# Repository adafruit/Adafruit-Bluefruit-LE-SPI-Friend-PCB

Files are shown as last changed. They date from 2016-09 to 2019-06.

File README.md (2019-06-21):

## Adafruit Bluefruit LE SPI Friend PCB

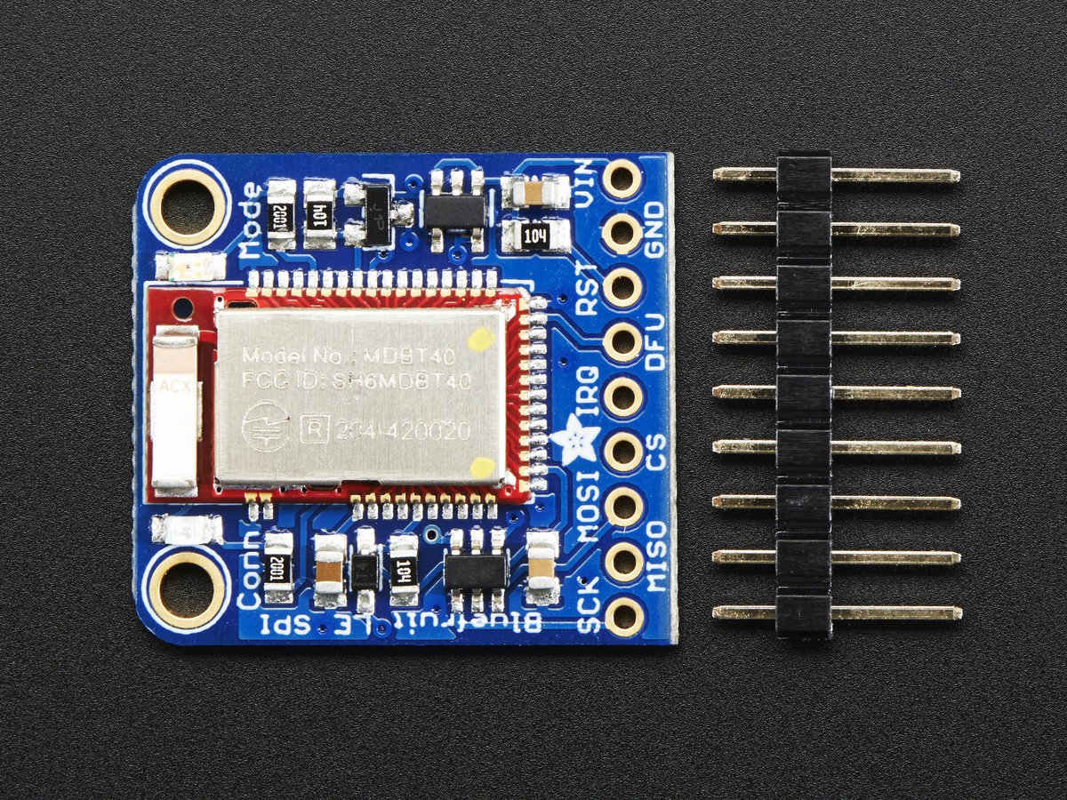
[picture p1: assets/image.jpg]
<a href="http://www.adafruit.com/products/2633"><br/>
Click here to purchase one from the Adafruit shop</a>

PCB files for the Adafruit Bluefruit LE SPI Friend PCB. Format is EagleCAD schematic and board layout
* https://www.adafruit.com/product/2633

### Description

The Bluefruit LE SPI Friend makes it easy to add Bluetooth Low Energy connectivity to anything with 4 or 5 GPIO pins. With SPI, you don't have to worry about baud rates, flow control, or giving up a hardware UART port. Connect to your Arduino or other microcontroller using the common four-pin SPI interface (MISO, MOSI, SCK and CS) plus a 5th GPIO pin for interrupts (to let the Arduino know when data or a response is ready).

This multi-function module can do quite a lot! For most people, they'll be very happy to use the standard Nordic UART RX/TX connection profile. In this profile, the Bluefruit acts as a data pipe, that can 'transparently' transmit back and forth from your iOS or Android device. You can use our iOS App or Android App, or write your own to communicate with the UART service.

### License

Adafruit invests time and resources providing this open source design, please support Adafruit and open-source hardware by purchasing products from [Adafruit](https://www.adafruit.com)!

Designed by Limor Fried/Ladyada for Adafruit Industries.

Creative Commons Attribution/Share-Alike, all text above must be included in any redistribution. See license.txt for additional details.

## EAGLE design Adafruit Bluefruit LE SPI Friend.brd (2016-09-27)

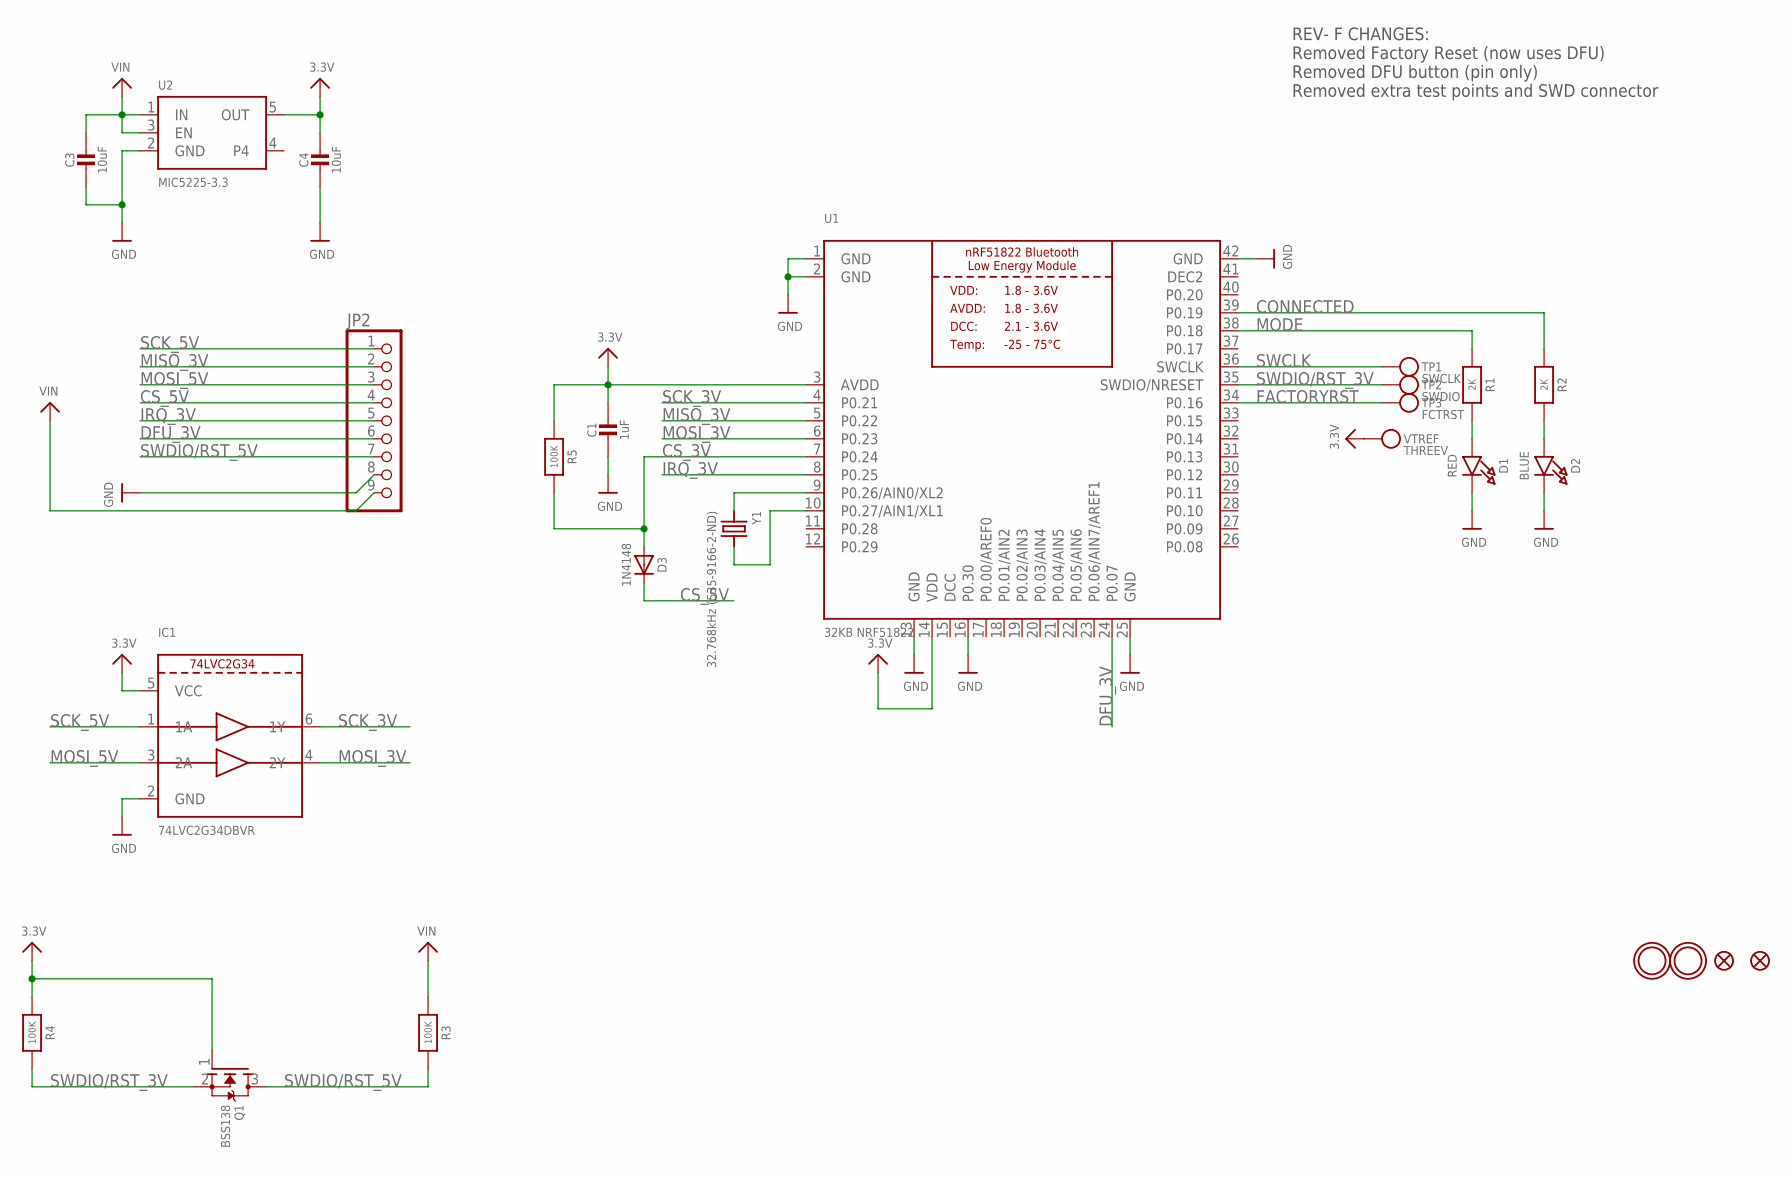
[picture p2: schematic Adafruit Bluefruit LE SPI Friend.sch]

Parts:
C1: 1uF; 0805_10MGAP
C3: 10uF; 0805-NO
C4: 10uF; 0805_10MGAP
D1: RED; CHIPLED_0805_NOOUTLINE
D2: BLUE; CHIPLED_0805_NOOUTLINE
D3: 1N4148; SOD-323
FID1, FID3: FIDUCIAL""; FIDUCIAL_1MM
IC1: 74LVC2G34DBVR; SOT23-6
JP2: HEADER-1X970MIL; 1X09_ROUND_70
Q1: BSS138; SOT23-WIDE@1
R1, R2: 2K; _0805MP
R3, R4: 100K; 0805-NO
R5: 100K; _0805MP
TP1: SWCLK; PAD-1.5X2.0
TP2: SWDIO; PAD-1.5X2.0
TP3: FCTRST; PAD-1.5X2.0
U1: 32KB NRF51822; BLE_MODULE_RAYTAC_MDBT40
U2: MIC5225-3.3; SOT23-5
U$28, U$29: MOUNTINGHOLE2.5; MOUNTINGHOLE_2.5_PLATED
VTREF: THREEV; PAD-1.5X2.0
Y1: 32.768kHz (535-9166-2-ND); CRYSTAL_CYL_2X6MM_SMT

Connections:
3.3V: C1.1, C4.1, IC1.5 (VCC), Q1.1 (G), R4.1, R5.1, U1.3 (AVDD), U1.14 (VDD), U2.5 (OUT), VTREF.P$1
CONNECTED: R2.1, U1.39 (P0.19)
CS_3V: D3.A, R5.2, U1.7 (P0.24)
CS_5V: D3.C, JP2.4
DCC: U1.15 (DCC)
DEC2: U1.41 (DEC2)
DFU_3V: JP2.6, U1.24 (P0.07)
FACTORYRST: TP3.P$1, U1.34 (P0.16)
GND: C1.2, C3.2, C4.2, D1.C, D2.C, IC1.2 (GND), JP2.8, U1.1 (GND), U1.2 (GND), U1.13 (GND), U1.16 (P0.30), U1.25 (GND), U1.42 (GND), U2.2 (GND)
IRQ_3V: JP2.5, U1.8 (P0.25)
MISO_3V: JP2.2, U1.5 (P0.22)
MODE: R1.1, U1.38 (P0.18)
MOSI_3V: IC1.4 (2Y), U1.6 (P0.23)
MOSI_5V: IC1.3 (2A), JP2.3
unnamed: U1.9 (P0.26/AIN0/XL2), Y1.1
unnamed: U1.10 (P0.27/AIN1/XL1), Y1.2
unnamed: D1.A, R1.2
unnamed: D2.A, R2.2
SCK_3V: IC1.6 (1Y), U1.4 (P0.21)
SCK_5V: IC1.1 (1A), JP2.1
SWCLK: TP1.P$1, U1.36 (SWCLK)
SWDIO/RST_3V: Q1.2 (S), R4.2, TP2.P$1, U1.35 (SWDIO/NRESET)
SWDIO/RST_5V: JP2.7, Q1.3 (D), R3.2
VIN: C3.1, JP2.9, R3.1, U2.1 (IN), U2.3 (EN)

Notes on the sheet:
REV- F CHANGES: Removed Factory Reset (now uses DFU) Removed DFU button (pin only) Removed extra test points and SWD connector

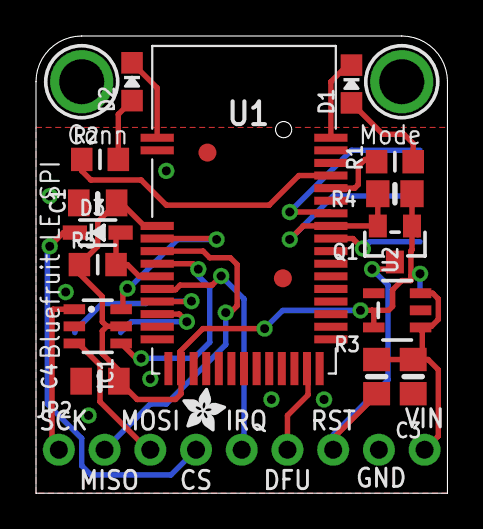
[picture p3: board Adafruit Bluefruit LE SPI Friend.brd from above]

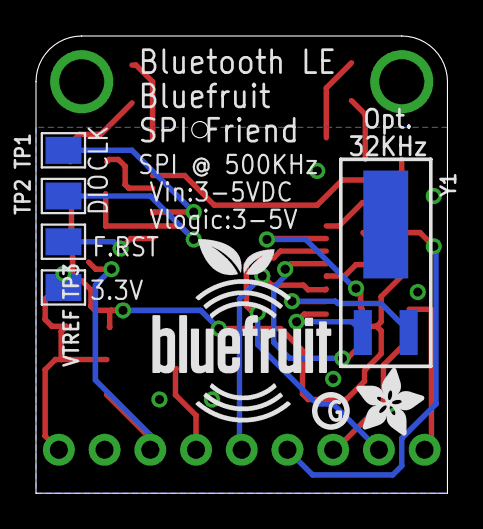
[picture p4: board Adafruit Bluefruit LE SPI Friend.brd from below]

Board: 2 copper layers, 22.9 x 25.4 mm, 29 parts (8 on the bottom side), 22 nets.

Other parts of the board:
U$3: ADAFRUIT_2.5MM
U$9: BLUEFRUITLOGO_100MM
U$17: ADAFRUIT_3.5MM
U$18: PCBFEAT-REV-040

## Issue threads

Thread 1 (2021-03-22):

How to burn BluefruitLE bootloader?

myst729, 2021-03-22:
Thank you for making this open sourced. I'm trying to make some compatible change based on your design (empower my homemade AVR keyboard with BLE). I've used a Bluefruit LE UART Friend before, with built-in BluefruitLE Firmware. It work quite well. So for my own hand-crafted SPI Friend, what should I do to burn the BluefruitLE bootloader? Any tutorials out there?

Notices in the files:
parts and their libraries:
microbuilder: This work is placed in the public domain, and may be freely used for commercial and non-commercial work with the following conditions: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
